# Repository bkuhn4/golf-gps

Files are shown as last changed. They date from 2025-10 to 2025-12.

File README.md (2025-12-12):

# EE 333 Pocket Caddy

## Description
Pocket Caddy is a handheld golf GPS and shot tracking device designed to help golfers track their performance and environmental conditions. It utilizes a high-precision u-blox GNSS module to measure shot distances and logs them to a micro SD card along with real-time temperature and humidity data. The device features an OLED display for easy navigation, a battery fuel gauge for power management, and a robust menu system for managing user profiles and reviewing shot history.

## Features
- **GPS Distance Tracking:** Calculates precise distances between shot start and end points using the Vincenty formula.
- **Shot Logging:** Records club used, distance, temperature, humidity, date, and time to an SD card.
- **Environmental Monitoring:** Real-time display of temperature and humidity using the SHT31 sensor.
- **Battery Management:** Monitors battery voltage, state of charge (SOC), and current consumption.
- **User Profiles:** Supports multiple user profiles for organizing shot data.
- **OLED Interface:** Clear, high-contrast menu system navigated via physical buttons.

## Hardware

The Pocket Caddy hardware is built around the ESP32-C3 microcontroller and includes the following components:

*   **Microcontroller:** Espressif ESP32-C3-WROOM-02
*   **GNSS Module:** u-blox NEO-M9N (High-precision GPS/GLONASS/Galileo)
*   **GNSS Antenna:** Taoglas SGGP.25.4.A.02
*   **Display:** 0.96" OLED I2C Display (128x64 pixels)
*   **Sensors:**
    *   Sensirion SHT30-DIS (Temperature & Humidity)
    *   TI BQ27441-G1 (LiPo Fuel Gauge)
*   **Storage:** Micro SD Card Slot
*   **Power:**
    *   USB-C Connector (Charging & Data)
    *   LiPo Battery Connector
    *   Coin Cell Battery Backup (for GNSS hot start)

## Pin Configuration

| Component | Pin Name | ESP32-C3 Pin |
| :--- | :--- | :--- |
| **Buttons** | Button 1 (Down) | GPIO 9 |
| | Button 2 (Up) | GPIO 20 |
| | Button 3 (Select) | GPIO 2 |
| **I2C Bus** | SDA | GPIO 10 |
| | SCL | GPIO 4 |
| **GPS** | Enable | GPIO 3 |
| | Reset | GPIO 21 |

## Dependencies

To compile the firmware, you will need to install the following libraries via the Arduino Library Manager:

*   **SparkFun u-blox GNSS Arduino Library** by SparkFun Electronics
*   **SparkFun BQ27441 LiPo Fuel Gauge Arduino Library** by SparkFun Electronics
*   **Adafruit SHT31 Library** by Adafruit
*   **U8g2** by olikraus

## Programming the Device

### First-Time Programming (Boot Mode)
When programming the device for the first time (or if it becomes unresponsive), you need to manually enter the bootloader mode:
1.  Hold down the **BOOT** button.
2.  While holding BOOT, press and release the **RESET** button.
3.  Release the **BOOT** button.
4.  The device is now in boot mode and ready to accept firmware.

### Arduino IDE Settings
To ensure the device communicates correctly over USB for serial monitoring and subsequent uploads:
1.  **Install Board Support:** Ensure the **esp32** board library by Espressif Systems is installed. If not, go to `Tools > Board > Boards Manager` and search `"esp32"`.
2.  **Select Board:** Go to `Tools > Board > esp32 > ESP32C3 Dev Module`.
3.  **USB CDC On Boot:** To avoid having to manually enter boot mode each time, go to `Tools > USB CDC On Boot > Enabled`.
4.  Select the correct COM port. `Tools > Port > COM#`.

## Usage

### Controls
The device is operated using three buttons:
-   **Button 1 (Down):** Navigate down in menus.
-   **Button 2 (Up):** Navigate up in menus.
-   **Button 3 (Select/Back):**
    -   **Short Press:** Select item / Confirm action.
    -   **Long Press:** Go back to the previous menu.

### Main Menu Options
-   **Track Shot:** Start a new shot tracking session. Mark your start point, go to your ball, mark the end point, and select the club used.
-   **Sensor View:** Displays raw sensor data including GPS coordinates (Lat/Lon), Satellite count (SIV), Temperature, Humidity, and Battery stats.
-   **Shot Log:** Review historical shot data organized by club.
-   **Settings:**
    -   **Units:** Toggle between Imperial (Yards/Fahrenheit) and Metric (Meters/Celsius).
    -   **Profiles:** Create, Rename, or Remove user profiles.

## Authors and acknowledgment
-   **Brady Kuhn**: Hardware | Software
-   **Bryan York**

## Project status
Active Development - Version 0.1

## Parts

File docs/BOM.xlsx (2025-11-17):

Quantity | Reference(s) | Description | Package | Part Number | Manufacturer | Vendor PN | Notes | Link
1 | AE1 | RF ANT 1.575/1.602GHZ CER PATCH |  | SGGP.25.2.A.02 | Taoglas Limited | 931-1450-1-ND |  | https://www.digikey.com/en/products/detail/taoglas-limited/SGGP-25-2-A-02/6362788?gclsrc=aw.ds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
1 | BT1 | 1500mAh LiPo Battery |  |  | GYMIN | B0CRP2G3XN | Amazon | https://www.amazon.com/GYMIN-Rechargeable-Replacement-Steelseries-Wireless/dp/B0CRP2G3XN
1 | BT2 | BATTERY RETAINER COIN 20MM SMD |  | 3002 | Keystone Electronics | 36-3002-ND | ETG Stock
7 | C1-C6, C8 | CAP CER 10UF 16V X5R 0805 | C0805 | CL21A106KOQNNNG | Samsung Electro-Mechanics | 1276-6455-1-ND | ETG Stock
8 | C7, C9, C11, C12, C15, C16, C19, C20 | CAP CER 0.1UF 50V X7R 0603 | C0603 | CL10B104KB8NNNC | Samsung Electro-Mechanics | 1276-1000-1-ND | ETG Stock
2 | C10, 21 | CAP CER 1UF 25V X5R 0603 | C0603 | CL10A105KA8NNNC | Samsung Electro-Mechanics | 1276-1102-1-ND | ETG Stock
2 | C13, C14 | CAP CER 18PF 50V C0G/NP0 0603 | C0603 | CL10C180JB81PNC | Samsung Electro-Mechanics | 1276-2208-1-ND
3 | D1, D3, D4 | LED RED CLEAR SMD 0805 | D0805 | LTST-C171KRKT | Lite-On Inc. | 160-1427-1-ND
1 | D2 | TVS DIODE 5.5VWM SOT143B | SOT-143B | PRTR5V0U2X,215 | Nexperia USA Inc. | 1727-3884-1-ND
2 | D5, D6 | LED GREEN CLEAR SMD 0805 | D0805 | LTST-C170GKT | Lite-On Inc. | 160-1179-1-ND | ETG Stock
1 | D7 | DIODE ARR SCHOTT 30V 200MA SOT23 | SOT-23 | BAT54C | Diotec Semiconductor | 4878-BAT54CCT-ND |  | https://www.digikey.com/en/products/detail/diotec-semiconductor/bat54c/13163831
1 | F1 | PTC RESET FUSE 6V 1A 1206 | 1206 | 0ZCJ0100FF2E | Bel Fuse Inc. | 5923-0ZCJ0100FF2ECT-ND
1 | J1 | CONN RCP USB2.0 TYP C 24P SMD RA |  | USB4105-GF-A | GCT | 2073-USB4105-GF-ACT-ND |  | https://www.digikey.com/en/products/detail/gct/usb4105-gf-a-120/14559037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
1 | J2 | TERM BLK 3P SIDE ENT 2.54MM PCB | P=2.54mm | 282834-3 | TE Connectivity | A98334-ND | ETG Stock
1 | J3 | Conn_01x03_Pin | P=2.54mm |  |  |  | ETG Stock
1 | J4 | Conn_02x04 | P=2.54mm |  |  |  | ETG Stock
1 | J5 | Conn_01x04 | P=2.54mm |  |  |  | ETG Stock
1 | J6 | CONN MICRO SD CARD R/A SMD |  | 1040310811 | Molex | WM6357CT-ND |  | https://www.digikey.com/en/products/detail/molex/1040310811/2370379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
1 | L1 | FIXED IND 1.5UH SMD |  | VLS3012CX-1R5M-1 | TDK Corporation | 445-VLS3012CX-1R5M-1CT-ND
1 | L2 |  |  |  |  |  | DNP. Use 0603 0 Ohm resistor
1 | Q1 | MOSFET P-CH 20V 4.2A SOT23 | SOT-23-3 | DMG2305UX-7 | Diodes Incorporated | DMG2305UX-7DICT-ND |  | https://www.digikey.com/en/products/detail/diodes-incorporated/dmg2305ux-7/4340667
2 | R1, R3 | RES 27 OHM 5% 1/10W 0603 | R0603 | RC0603JR-0727RL | YAGEO | 311-27GRCT-ND |  | https://www.digikey.com/en/products/detail/yageo/RC0603JR-0727RL/726751
1 | R2 | RES 1.3K OHM 5% 1/10W 0603 | R0603 | RC0603JR-071K3L | YAGEO | 311-1.3KGRCT-ND |  | https://www.digikey.com/en/products/detail/yageo/RC0603JR-071K3L/726686
8 | R4, R11-R13, R15-R18 | 10 kOhms ±1% 0.125W, 1/8W | R0603 | RNCP0603FTD10K0 | Stackpole Electronics Inc | RNCP0603FTD10K0CT-ND | ETG Stock
5 | R5, R8-R10, R14 | RES 1K OHM 1% 1/8W 0603 | R0603 | RNCP0603FTD1K00 | Stackpole Electronics Inc | RNCP0603FTD1K00CT-ND | ETG Stock
2 | R6, R7 | RES 5.1K OHM 1% 1/10W 0603 | R0603 | RMCF0603FT5K10 | Stackpole Electronics Inc | RMCF0603FT5K10CT-ND
1 | R19 | RES 0.01 OHM 1% 1W 1206 | R1206 | CSNL1206FT10L0 | Stackpole Electronics Inc | CSNL1206FT10L0CT-ND | 1% tolerance, 1W rating, 50ppm TCR
1 | R20 | RES 470K OHM 5% 1/8W 0805 | R0805 | RMCF0805JT470K | Stackpole Electronics Inc | RMCF0805JT470KCT-ND
2 | R21, R22 | RES 1M OHM 1% 1/8W 0805 | R0805 | RMCF0805FT1M00 | Stackpole Electronics Inc | RMCF0805FT1M00CT-ND
1 | SW1 | SWITCH SLIDE SPDT 200MA 30V | P=2.54mm | EG1218 | E-Switch | EG1903-ND | ETG Stock
4 | SW2-SW5 | SWITCH TACTILE SPST-NO 0.05A 12V |  |  |  |  | ETG Stock
1 | U1 | IC BATT CHG LI-ION 1CELL 20QFN | 20-VFQFN | MCP73871-1AAI/ML | Microchip Technology | MCP73871-1AAI/ML-ND |  | https://www.digikey.com/en/products/detail/microchip-technology/mcp73871-1aai-ml/7928179
1 | U2 | IC REG BUCK BST 3.3V 900MA 10SON | 10-WFDFN | TPS63031DSKR | Texas Instruments | 296-39461-1-ND |  | https://www.digikey.com/en/products/detail/texas-instruments/TPS63031DSKR/2048021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
1 | U3 | ESP32-C3-WROOM-02-H4 | 32-SMD Module | ESP32-C3-WROOM-02-H4 | Espressif Systems | 1965-ESP32-C3-WROOM-02-H4CT-ND |  | https://www.digikey.com/en/products/detail/espressif-systems/esp32-c3-wroom-02-h4/14553033
1 | U4 | M9 STANDARD PRECISION GNSS MOD | 24-SMD Module | NEO-M9N-00B | u-blox | 672-NEO-M9N-00BCT-ND |  | https://www.digikey.com/en/products/detail/u-blox/neo-m9n-00b/12149174
1 | U5 | SENSOR HUMID/TEMP 5V I2C 2% SMD | 8-VFDFN | SHT30-DIS-B2.5KS | Sensirion AG | 1649-1009-1-ND |  | https://www.digikey.com/en/products/detail/sensirion-ag/SHT30-DIS-B2-5KS/5872250
1 | U6 | IC FUEL GAUGE LI-ION 1CELL 12SON | 12-VFDFN | BQ27411DRZT-G1A | Texas Instruments | 296-37269-1-ND |  | https://www.digikey.com/en/products/detail/texas-instruments/BQ27427YZFR/17748369
1 | Y1 | CRYSTAL 32.7680KHZ 12.5PF SMD | 2-SMD (3.2x1.5) | ABS07-32.768KHZ-T | Abracon LLC | 535-9542-1-ND |  | https://www.digikey.com/en/products/detail/abracon-llc/ABS07-32-768KHZ-T/1236858
73 | Total Part Count

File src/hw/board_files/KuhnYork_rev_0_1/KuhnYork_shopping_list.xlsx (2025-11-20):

Digi-Key: Shopping Cart
Index | Quantity | Part Number | Manufacturer Part Number | Description | Customer Reference | Available | Backorder | Unit Price | Extended Price USD
1 | 2 | 931-1450-1-ND | SGGP.25.2.A.02 | RF ANT 1.575/1.602GHZ CER PATCH | KUHN, YORK | 2 | 0 | 7.2 | 14.40
2 | 2 | 4878-BAT54CCT-ND | BAT54C | DIODE ARR SCHOTT 30V 200MA SOT23 | KUHN, YORK | 2 | 0 | 0.12 | 0.24
3 | 2 | 1740-ESDALD05UJ2XCT-ND | ESDALD05UJ2X | TVS DIODE 5VWM 17VC SOT143 | KUHN, YORK | 2 | 0 | 0.47 | 0.94
4 | 2 | 2073-USB4105-GF-ACT-ND | USB4105-GF-A | CONN RCP USB2.0 TYP C 24P SMD RA | KUHN, YORK | 2 | 0 | 0.78 | 1.56
5 | 2 | 5923-0ZCJ0100FF2ECT-ND | 0ZCJ0100FF2E | PTC RESET FUSE 6V 1A 1206 | KUHN, YORK | 2 | 0 | 0.25 | 0.50
6 | 2 | WM6357CT-ND | 1040310811 | CONN MICRO SD CARD R/A SMD | KUHN, YORK | 2 | 0 | 2.04 | 4.08
7 | 2 | 445-VLS3012CX-1R5M-1CT-ND | VLS3012CX-1R5M-1 | FIXED IND 1.5UH SMD | KUHN, YORK | 2 | 0 | 0.24 | 0.48
8 | 18 | RNCP0603FTD10K0CT-ND | RNCP0603FTD10K0 | RES 10K OHM 1% 1/8W 0603 | KUHN, YORK | 18 | 0 | 0.011 | 0.20
9 | 10 | RNCP0603FTD1K00CT-ND | RNCP0603FTD1K00 | RES 1K OHM 1% 1/8W 0603 | KUHN, YORK | 10 | 0 | 0.01 | 0.10
10 | 2 | CSNL1206FT10L0CT-ND | CSNL1206FT10L0 | RES 0.01 OHM 1% 1W 1206 | KUHN, YORK | 2 | 0 | 0.58 | 1.16
11 | 2 | MCP73871-1AAI/ML-ND | MCP73871-1AAI/ML | IC BATT CHG LI-ION 1CELL 20QFN | KUHN, YORK | 2 | 0 | 2.41 | 4.82
12 | 2 | 296-39461-1-ND | TPS63031DSKR | IC REG BUCK BST 3.3V 900MA 10SON | KUHN, YORK | 2 | 0 | 2.14 | 4.28
13 | 2 | 296-37269-1-ND | BQ27411DRZT-G1A | IC FUEL GAUGE LI-ION 1CELL 12SON | KUHN, YORK | 2 | 0 | 3.18 | 6.36
14 | 2 | 1649-1009-1-ND | SHT30-DIS-B2.5KS | SENSOR HUMID/TEMP 5V I2C 2% SMD | KUHN, YORK | 2 | 0 | 2.7 | 5.40
15 | 2 | 535-9542-1-ND | ABS07-32.768KHZ-T | CRYSTAL 32.7680KHZ 12.5PF SMD | KUHN, YORK | 2 | 0 | 0.61 | 1.22

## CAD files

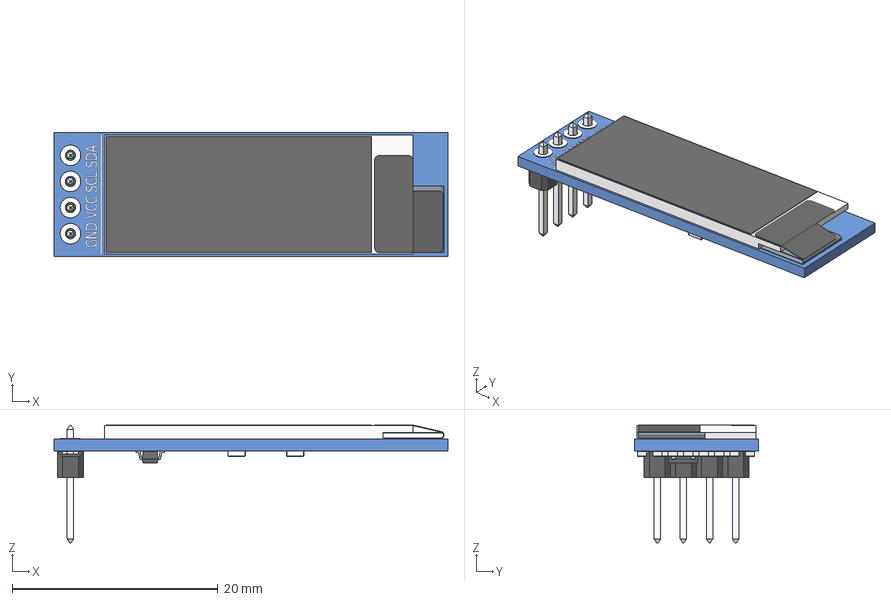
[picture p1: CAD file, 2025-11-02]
src/hw/board_files/3d_models/OLED_0.91_128x32.stp
38.3 x 12.1 x 11.5 mm
OLED_0.91_128x32
Pin Header 4 x 1 TH 2.54mm Pitch
RESC-0603 x 13
2SD0601A

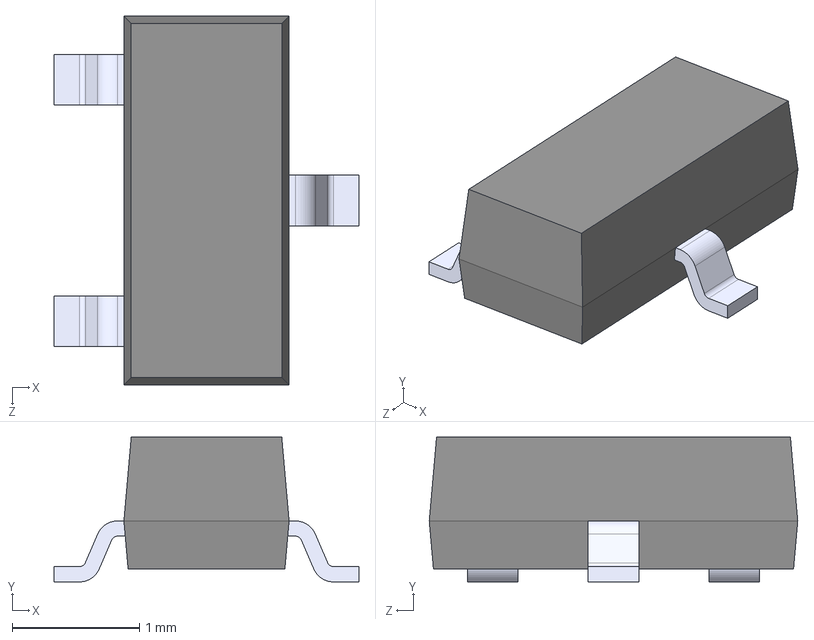
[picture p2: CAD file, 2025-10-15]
src/hw/board_files/3d_models/DMG2305UX-7.STEP
2.40 x 1.14 x 2.90 mm

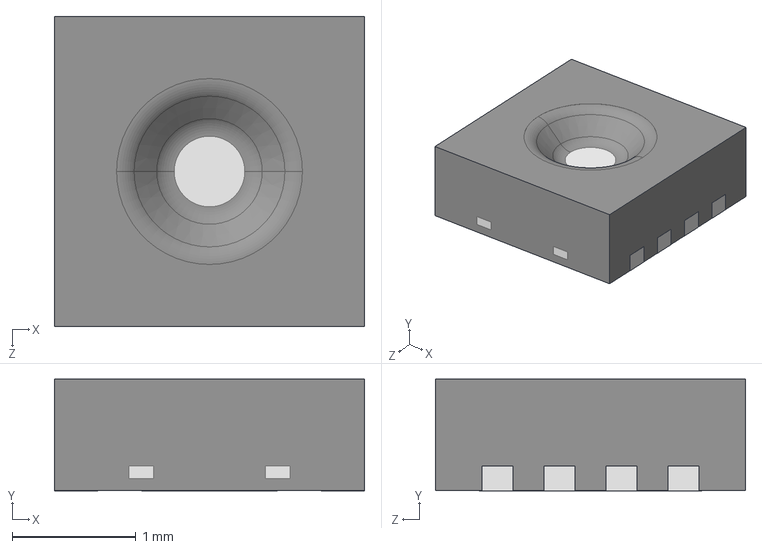
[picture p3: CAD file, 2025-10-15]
src/hw/board_files/3d_models/SHT30-DIS-B2.5KS.step
2.50 x 0.901 x 2.50 mm

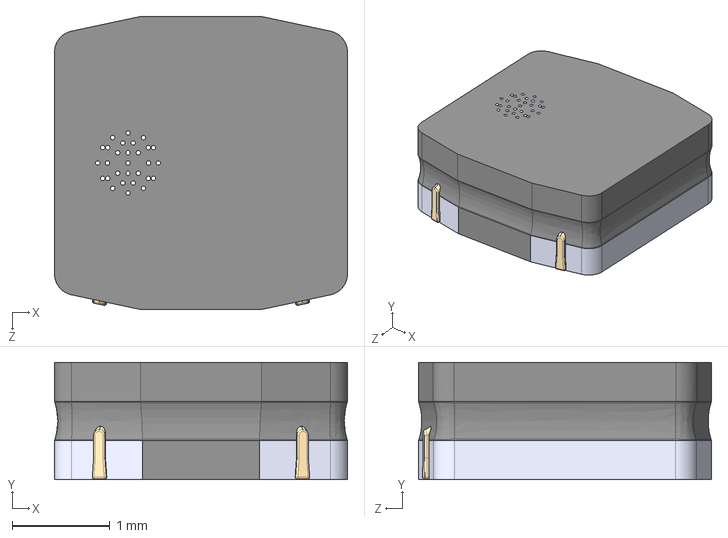
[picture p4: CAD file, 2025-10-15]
src/hw/board_files/3d_models/VLS3012CX-1R5M-1.STEP
3.00 x 1.20 x 3.00 mm

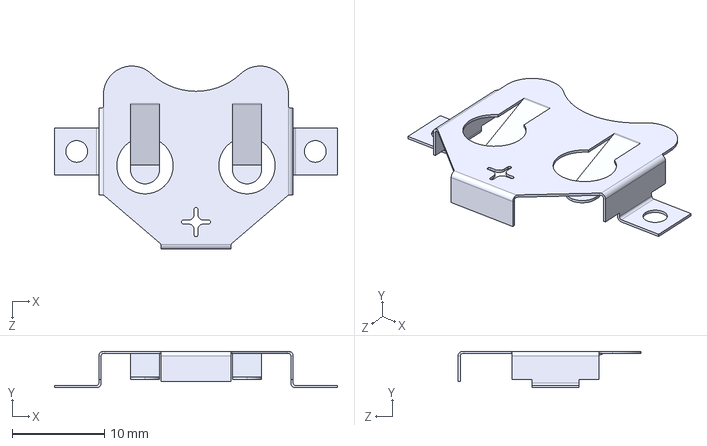
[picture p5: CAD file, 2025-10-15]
src/hw/board_files/3d_models/3002.step
30.7 x 3.96 x 19.9 mm

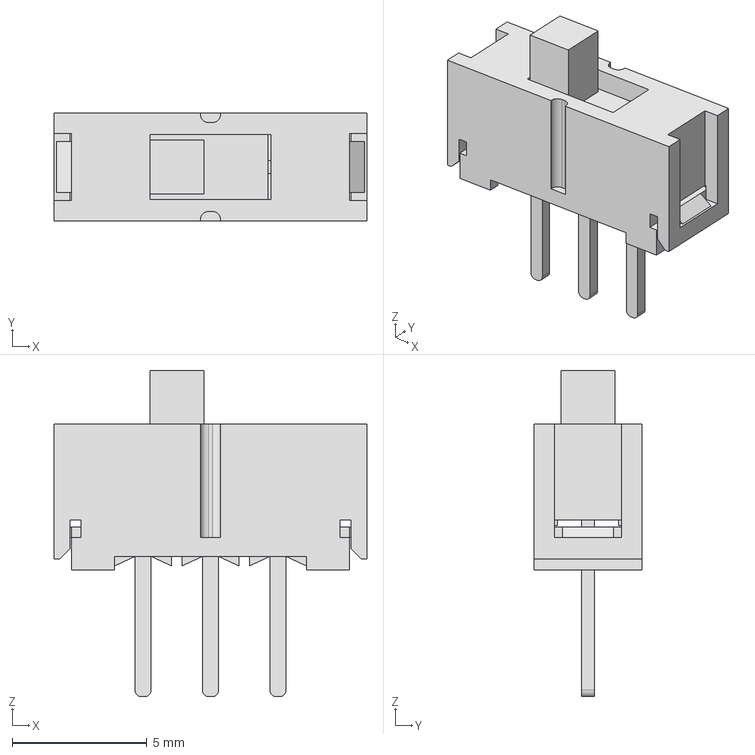
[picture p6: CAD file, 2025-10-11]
src/hw/board_files/3d_models/141_EG1218.stp
11.6 x 4.00 x 12.1 mm

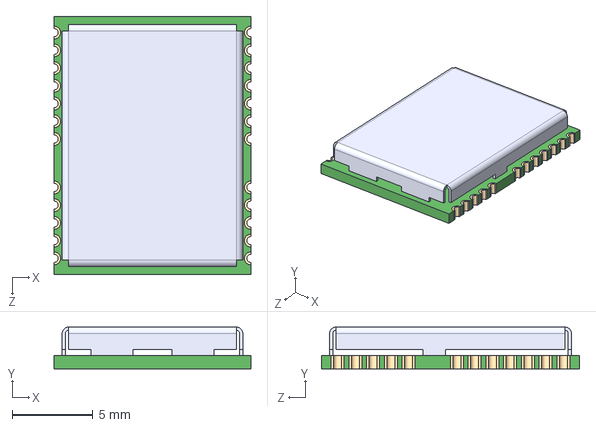
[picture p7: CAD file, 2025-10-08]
src/hw/board_files/3d_models/NEO-M9N-00B.STEP
12.2 x 2.60 x 16.0 mm

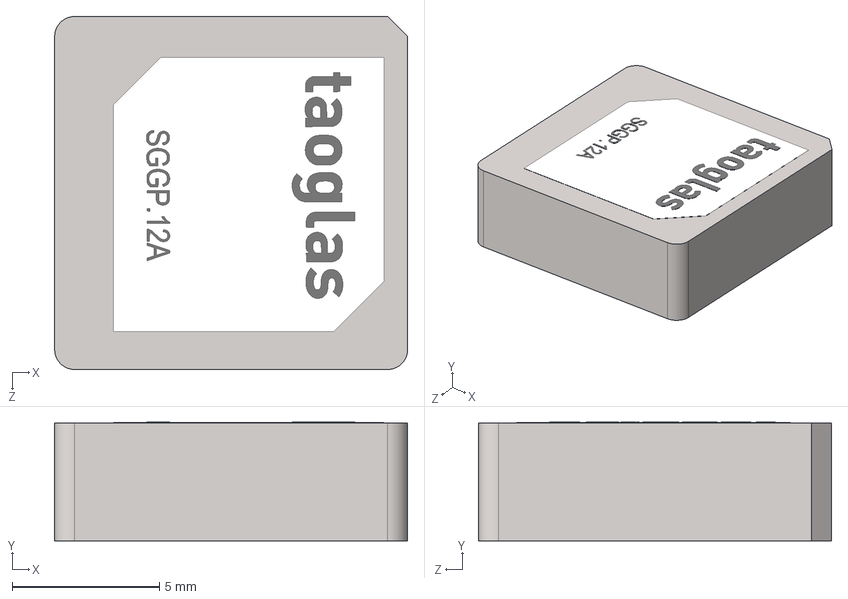
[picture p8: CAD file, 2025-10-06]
src/hw/board_files/3d_models/SGGP.12.4.A.02_Web.STEP
12.0 x 4.03 x 12.0 mm

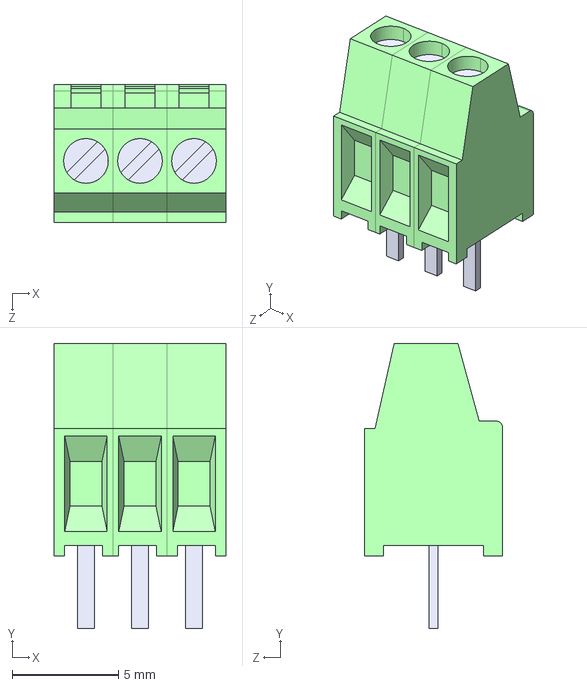
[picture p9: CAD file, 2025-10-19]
src/hw/board_files/3d_models/282834-3.STEP
8.08 x 13.4 x 6.50 mm

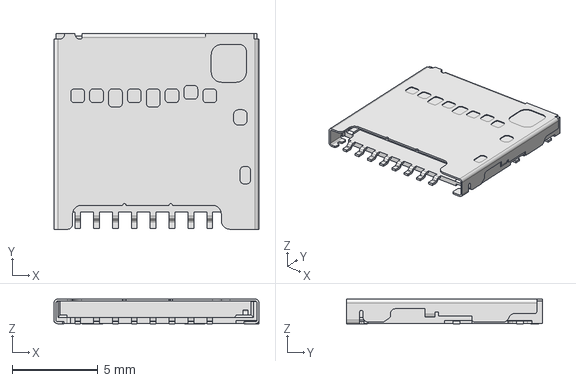
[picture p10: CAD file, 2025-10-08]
src/hw/board_files/3d_models/1040310811.stp
11.9 x 11.4 x 1.45 mm

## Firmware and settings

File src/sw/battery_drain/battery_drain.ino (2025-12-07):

#include <Wire.h>
#include <WiFi.h>
#include <Preferences.h>
#include <SparkFunBQ27441.h>
#include <Adafruit_GFX.h>
#include <Adafruit_SSD1306.h>

// --- HARDWARE CONFIG ---
#define SDA_PIN 10
#define SCL_PIN 4 

// --- BUTTONS (Adjust pins to match your PCB) ---
// Connect buttons between Pin and GND (Active LOW)
#define BTN_LOAD_PIN  9   // Button 1: Toggle High Load
#define BTN_SLEEP_PIN 20  // Button 2: Force Sleep/Relax
#define BTN_SAVE_PIN  2   // Button 3: Save Data

// --- BATTERY SETTINGS ---
#define DESIGN_CAPACITY 1500 
#define TERMINATE_VOLTAGE 3000 // 3.0V

Adafruit_SSD1306 display(128, 64, &Wire, -1);
Preferences preferences;

bool loadEnabled = false;
unsigned long lastButtonPress = 0;

// Helper to send GAUGE_EN (0x0021) since executeControlWord is private
bool enableGauge() {
  Wire.beginTransmission(0x55); // BQ27441 I2C Address
  Wire.write(0x00);             // Control() Command
  Wire.write(0x21);             // LSB of GAUGE_EN
  Wire.write(0x00);             // MSB of GAUGE_EN
  return Wire.endTransmission() == 0;
}

void setup() {
  Serial.begin(115200);
  Wire.begin(SDA_PIN, SCL_PIN);
  
  // Setup Buttons
  pinMode(BTN_LOAD_PIN, INPUT_PULLUP);
  pinMode(BTN_SLEEP_PIN, INPUT_PULLUP);
  pinMode(BTN_SAVE_PIN, INPUT_PULLUP);

  // Setup Wakeup Source (Any button press wakes the ESP32-C3)
  // Mask is a bitmask of pins. If using pins 3,4,5:
  // Note: ESP32-C3 Deep Sleep wakeup usually works best on RTC GPIOs.
  // We will assume standard GPIO wakeup for C3:
  esp_deep_sleep_enable_gpio_wakeup(BIT(BTN_LOAD_PIN) | BIT(BTN_SLEEP_PIN) | BIT(BTN_SAVE_PIN), ESP_GPIO_WAKEUP_GPIO_LOW);

  // Init OLED
  if(!display.begin(SSD1306_SWITCHCAPVCC, 0x3C)) { 
    Serial.println(F("OLED Fail")); for(;;);
  }
  display.clearDisplay();
  display.setTextColor(WHITE);

  // Init BQ27411
  if (!lipo.begin()) {
    display.setCursor(0,0);
    display.println("Gauge Not Found!");
    display.display();
    while (1);
  }

  // --- RESTORE DATA ---
  preferences.begin("bat_data", true);
  unsigned int savedCap = preferences.getUInt("learned_cap", 0);
  preferences.end();
  
  // If we have valid saved data, load it. Otherwise default.
  if (savedCap > 1000 && savedCap < 2000) {
    lipo.setCapacity(savedCap); 
  } else {
    lipo.setCapacity(DESIGN_CAPACITY);
  }
  
  // Force Learning Mode ON
  if (enableGauge()) {
    Serial.println("Gauge Enabled (Impedance Track)");
  } else {
    Serial.println("Failed to Enable Gauge");
  }

  // Print Wake Reason
  esp_sleep_wakeup_cause_t wakeup_reason = esp_sleep_get_wakeup_cause();
  if (wakeup_reason == ESP_SLEEP_WAKEUP_GPIO) {
      Serial.println("Woke up via Button!");
  }
}

void loop() {
  // 1. Read Gauge
  unsigned int volts = lipo.voltage();
  int current = lipo.current(AVG);
  unsigned int soc = lipo.soc();
  unsigned int fcc = lipo.capacity(FULL);

  // 2. Handle Buttons
  if (millis() - lastButtonPress > 300) { // Simple debounce
    
    // BUTTON 1: TOGGLE LOAD
    if (digitalRead(BTN_LOAD_PIN) == LOW) {
      loadEnabled = !loadEnabled;
      if (loadEnabled) {
        WiFi.mode(WIFI_AP);
        WiFi.softAP("Drainer", "12345678");
      } else {
        WiFi.mode(WIFI_OFF);
      }
      lastButtonPress = millis();
    }

    // BUTTON 2: FORCE SLEEP
    if (digitalRead(BTN_SLEEP_PIN) == LOW) {
      goToSleep();
    }

    // BUTTON 3: SAVE
    if (digitalRead(BTN_SAVE_PIN) == LOW) {
      saveData();
      lastButtonPress = millis();
    }
  }

  // 3. Update Display
  display.clearDisplay();
  display.setCursor(0,0);
  
  if (loadEnabled) display.println(">> DRAINING <<");
  else if (current > 50) display.println(">> CHARGING <<");
  else display.println("-- IDLE/READY --");

  display.setCursor(0, 15);
  display.setTextSize(2);
  display.print(volts/1000.0, 2); display.print("V");
  
  display.setTextSize(1);
  display.setCursor(80, 15);
  display.print(soc); display.println("%");

  display.setCursor(0, 35);
  display.print("I: "); display.print(current); display.println(" mA");
  display.print("FCC: "); display.print(fcc); display.println(" mAh");

  display.setCursor(0, 55);
  display.print("[1]Load [2]Slp [3]Sav");
  
  display.display();

  // 4. Auto-Cutoff Logic
  if (loadEnabled) {
     // Heavy math to generate heat/load
     double x = 10.0;
     for(int i=0; i<1000; i++) x = sqrt(x+i);
     
     // Automatic safety stop
     if (volts <= TERMINATE_VOLTAGE) {
        loadEnabled = false;
        WiFi.mode(WIFI_OFF);
        // We go to sleep automatically to allow relax
        goToSleep();
     }
  }
  
  delay(200);
}

void goToSleep() {
  display.clearDisplay();
  display.setCursor(0,20);
  display.setTextSize(2);
  display.println("SLEEPING...");
  display.setTextSize(1);
  display.println("Press Btn to Wake");
  display.display();
  delay(2000);
  
  // The setup() defined the wakeup pins.
  // Start Deep Sleep. Everything (OLED, WiFi, CPU) turns off.
  // BQ27411 stays ALIVE.
  esp_deep_sleep_start();
}

void saveData() {
  unsigned int currentCap = lipo.capacity(FULL);
  preferences.begin("bat_data", false);
  preferences.putUInt("learned_cap", currentCap);
  preferences.end();
  
  display.clearDisplay();
  display.setCursor(0,20);
  display.println("SAVED TO FLASH!");
  display.print("Val: "); display.println(currentCap);
  display.display();
  delay(2000);
}

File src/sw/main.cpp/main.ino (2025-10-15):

/******************************************************************************
 * PROJECT:     Pocket Caddy - Golf GPS
 * FILE:        PocketCaddy_GolfGPS.ino
 * AUTHOR:      Brady Kuhn, Bryan York
 * DATE:        10/15/2025
 * VERSION:     0
 *
 * REQUIRED LIBRARIES:
 * - Wire.h                                (Built-in)
 * - SPI.h                                 (Built-in)
 * - SD.h                                  (Built-in with ESP32 core)
 * - Adafruit GFX Library                  (by Adafruit)
 * - Adafruit SSD1306                      (by Adafruit)
 * - SparkFun u-blox GNSS Arduino Library  (by SparkFun Electronics)
 * - SparkFun BQ27441 LiPo Fuel Gauge      (by SparkFun Electronics)
 * - Adafruit SHT31 Library                (by Adafruit)
 *
 * TODO: 
 *
 ******************************************************************************/

// --- PIN DEFINITIONS ---

// I2C Bus Pins (for OLED, Fuel Gauge, Temp/Hum Sensor, and GPS Module)
#define SCL_PIN         4   // I2C Clock
#define SDA_PIN         10  // I2C Data

// GPS Module Control Pins (Power and Reset)
#define GPS_EN_N_PIN    3
#define GPS_RESET_N_PIN 2

// SPI Bus Pin (for MicroSD Card)
#define SD_CS_PIN       5   // SPI Chip Select

// User Input Buttons
#define BTN_1_PIN       9   // BOOT button
#define BTN_2_PIN       20
#define BTN_3_PIN       21

// --- SETUP FUNCTION ---
void setup() {
  // Start serial for debugging output
  Serial.begin(115200);
  Serial.println("\n--- Pocket Caddy: Initializing GPIO Pins (I2C GPS) ---");

  // Initialize Button Pins
  pinMode(BTN_1_PIN, INPUT_PULLUP);
  pinMode(BTN_2_PIN, INPUT_PULLUP);
  pinMode(BTN_3_PIN, INPUT_PULLUP);
  Serial.println("Button pins initialized.");

  // Initialize GPS Control Pins
  pinMode(GPS_EN_N_PIN, OUTPUT);
  pinMode(GPS_RESET_N_PIN, OUTPUT);
  digitalWrite(GPS_EN_N_PIN, HIGH);   // Default state: GPS powered ON
  digitalWrite(GPS_RESET_N_PIN, HIGH); // Default state: GPS not in reset
  Serial.println("GPS control pins initialized.");

  // Initialize SD Card Chip Select Pin
  pinMode(SD_CS_PIN, OUTPUT);
  digitalWrite(SD_CS_PIN, HIGH); // Default state: SD card not selected
  Serial.println("SD Card CS pin initialized.");

  // Note: The I2C pins (SDA, SCL) and SPI pins (MOSI, MISO, SCK)
  // are configured by their respective library `begin()` calls (e.g., Wire.begin()).
  // No explicit pinMode() is needed for them here.

  Serial.println("\n--- Pin initialization complete. ---");
}

// --- MAIN LOOP ---
void loop() {
  // Intentionally empty.
}

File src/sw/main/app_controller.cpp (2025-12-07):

#include "app_controller.h"
#include "menu_handler.h" // Need full definition for drawActionScreen

AppController::AppController() {
    currentSensorView = 0;
    useMetric = false;
    currentClubIcon = nullptr;
    state = STATE_IDLE;
}

void AppController::begin(SdCardHandler* sdCardObj, GpsHandler* gpsObj, TempHumidSensor* tempObj, BatteryFuelGauge* batObj, TrackShot* trackShotObj) {
    sdCard = sdCardObj;
    gps = gpsObj;
    tempSensor = tempObj;
    battery = batObj;
    trackShot = trackShotObj;

    if (sdCard) {
        SystemSettings settings = sdCard->loadSettings();
        useMetric = settings.useMetric;
    }
}

void AppController::refreshChangeProfileMenu(MenuItem* menuItems) {
    if (!sdCard) return;
    Serial.println("Refreshing Change Profile Menu...");

    SystemSettings settings = sdCard->loadSettings();

    for (int i = 0; i < 5; i++) {
        menuItems[SETTINGS_CHANGE_SLOT_1 + i].title = "";
        menuItems[SETTINGS_CHANGE_SLOT_1 + i].isAction = true;
    }

    int count = sdCard->getProfiles(profileNames, 5);
    
    for (int i = 0; i < count; i++) {
        menuItems[SETTINGS_CHANGE_SLOT_1 + i].title = profileNames[i];
        if (strcmp(profileNames[i], settings.currentProfile) == 0) {
            menuItems[SETTINGS_CHANGE_SLOT_1 + i].icon = epd_bitmap_check_icon;
        } else {
            menuItems[SETTINGS_CHANGE_SLOT_1 + i].icon = epd_bitmap_user_icon;
        }
    }

    int backIndex = SETTINGS_CHANGE_SLOT_1 + count;
    menuItems[backIndex].title = "Back";
    menuItems[backIndex].icon = epd_bitmap_back_arrow_icon;
    menuItems[backIndex].isAction = false;
    
    menuItems[SETTINGS_PROFILES_CHANGE].numChildren = count + 1;
}

void AppController::refreshRemoveProfileMenu(MenuItem* menuItems) {
    if (!sdCard) return;
    Serial.println("Refreshing Remove Profile Menu...");

    for (int i = 0; i < 5; i++) {
        menuItems[SETTINGS_REMOVE_SLOT_1 + i].title = "";
        menuItems[SETTINGS_REMOVE_SLOT_1 + i].isAction = true;
    }

    int count = sdCard->getProfiles(profileNames, 5);
    
    for (int i = 0; i < count; i++) {
        menuItems[SETTINGS_REMOVE_SLOT_1 + i].title = profileNames[i];
        menuItems[SETTINGS_REMOVE_SLOT_1 + i].icon = epd_bitmap_user_icon;
    }

    int backIndex = SETTINGS_REMOVE_SLOT_1 + count;
    menuItems[backIndex].title = "Back";
    menuItems[backIndex].icon = epd_bitmap_back_arrow_icon;
    menuItems[backIndex].isAction = false;
    
    menuItems[SETTINGS_PROFILES_REMOVE].numChildren = count + 1;
}

void AppController::refreshRenameProfileMenu(MenuItem* menuItems) {
    if (!sdCard) return;
    Serial.println("Refreshing Rename Profile Menu...");

    for (int i = 0; i < 5; i++) {
        menuItems[SETTINGS_RENAME_SLOT_1 + i].title = "";
        menuItems[SETTINGS_RENAME_SLOT_1 + i].isAction = true;
    }

    int count = sdCard->getProfiles(profileNames, 5);
    
    for (int i = 0; i < count; i++) {
        menuItems[SETTINGS_RENAME_SLOT_1 + i].title = profileNames[i];
        menuItems[SETTINGS_RENAME_SLOT_1 + i].icon = epd_bitmap_user_icon;
    }

    int backIndex = SETTINGS_RENAME_SLOT_1 + count;
    menuItems[backIndex].title = "Back";
    menuItems[backIndex].icon = epd_bitmap_back_arrow_icon;
    menuItems[backIndex].isAction = false;
    
    menuItems[SETTINGS_PROFILES_RENAME].numChildren = count + 1;
}

void AppController::refreshUnitsMenu(MenuItem* menuItems) {
    Serial.println("Refreshing Units Menu...");
    if (useMetric) {
        menuItems[SETTINGS_UNITS_IMPERIAL].icon = epd_bitmap_blank_icon;
        menuItems[SETTINGS_UNITS_METRIC].icon = epd_bitmap_check_icon;
    } else {
        menuItems[SETTINGS_UNITS_IMPERIAL].icon = epd_bitmap_check_icon;
        menuItems[SETTINGS_UNITS_METRIC].icon = epd_bitmap_blank_icon;
    }
}

void AppController::refreshShotLogClubs(MenuItem* menuItems) {
    if (!sdCard) return;
    Serial.println("Refreshing Shot Log Clubs...");

    SystemSettings settings = sdCard->loadSettings();
    
    for (int i = 0; i < 5; i++) {
        menuItems[SL_CLUB_SLOT_1 + i].title = "";
        menuItems[SL_CLUB_SLOT_1 + i].isAction = false;
        menuItems[SL_CLUB_SLOT_1 + i].firstChild = SL_SHOT_SLOT_1;
        menuItems[SL_CLUB_SLOT_1 + i].numChildren = 0;
    }

    int count = sdCard->getUsedClubs(settings.currentProfile, clubNames, 5);

    for (int i = 0; i < count; i++) {
        menuItems[SL_CLUB_SLOT_1 + i].title = clubNames[i];
        menuItems[SL_CLUB_SLOT_1 + i].icon = epd_bitmap_club_icon;
    }

    int backIndex = SL_CLUB_SLOT_1 + count;
    menuItems[backIndex].title = "Back";
    menuItems[backIndex].icon = epd_bitmap_back_arrow_icon;
    menuItems[backIndex].isAction = false;
    menuItems[backIndex].parent = MAIN_SHOT_LOG;

    menuItems[MAIN_SHOT_LOG].numChildren = count + 1;
}

void AppController::refreshShotLogShots(MenuItem* menuItems, const char* club) {
    if (!sdCard) return;
    Serial.print("Refreshing Shot Log Shots for Club: ");
    Serial.println(club);

    SystemSettings settings = sdCard->loadSettings();
    
    for (int i = 0; i < 5; i++) {
        menuItems[SL_SHOT_SLOT_1 + i].title = "";
        menuItems[SL_SHOT_SLOT_1 + i].isAction = true;
    }

    int count = sdCard->getShotsForClub(settings.currentProfile, club, shotCache, 5);

    for (int i = 0; i < count; i++) {
        float dist = shotCache[i].distance;
        int day = (shotCache[i].date / 10000) % 100;
        int month = (shotCache[i].date / 100) % 100;
        
        snprintf(shotTitles[i], 32, "%.0f%s %d/%d", dist, useMetric ? "m" : "y", month, day);
        menuItems[SL_SHOT_SLOT_1 + i].title = shotTitles[i];
        menuItems[SL_SHOT_SLOT_1 + i].icon = epd_bitmap_placeholder_icon;
    }

    int backIndex = SL_SHOT_SLOT_1 + count;
    menuItems[backIndex].title = "Back";
    menuItems[backIndex].icon = epd_bitmap_back_arrow_icon;
    menuItems[backIndex].isAction = false;
}
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

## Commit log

2025-06-18 Changed to stand alone STM32. Added battery charger, USB C, and more.
    [golf-gps.kicad_pcb, golf-gps.kicad_sch, power.kicad_sch]
2025-06-19 Added BOM file, finishing sch
    [BOM-golf-gps.xlsx, golf-gps.kicad_sch, microcontroller.kicad_sch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]
2025-06-26 Added PI filter to antenna.
    [golf-gps.kicad_sch, microcontroller.kicad_sch, peripherals.kicad_sch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]
2025-06-27 Finished sch, started power section on PCB
    [golf-gps.kicad_pcb, golf-gps.kicad_sch, microcontroller.kicad_sch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]
2025-07-08 PCB Progress
    [golf-gps.kicad_pcb, peripherals.kicad_sch, power.kicad_sch]
2025-07-16 Added USBC to UART bridge for programming. Changed pinout. Added pinout spreadsheet in docs.
    [Golf GPS Pinout.xlsx, golf-gps.kicad_pcb, microcontroller.kicad_sch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]
2025-07-17 Finished new sch. Updated pinout. Started new PCB.
    [Golf GPS Pinout.xlsx, golf-gps.kicad_pcb, golf-gps.kicad_sch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]
2025-07-22 Removed USB to UART bridge, added VDDA decoupling, adjusted MCU pinout and updated spreadsheet
    [Golf GPS Pinout.xlsx, golf-gps.kicad_pcb, golf-gps.kicad_sch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]
2025-07-23 Updated pinout and spreadsheet, PCB changes
    [Golf GPS Pinout.xlsx, golf-gps.kicad_pcb, golf-gps.kicad_sch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]
2025-08-01 Figured out general component placement and made progress routing. Removed pullup resistor from MOSI, MISO, and SCK lines
    [golf-gps.kicad_pcb, peripherals.kicad_sch]
2025-08-02 Started filling out BOM
    [BOM-golf-gps.xlsx, golf-gps.kicad_pcb, golf-gps.kicad_sch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]
2025-08-06 PCB progress. Changed horizontal programming header to vertical.
    [golf-gps.kicad_pcb, microcontroller.kicad_sch, peripherals.kicad_sch]
2025-09-20 Started ESP32 schematic
    [BOM.xlsx, Golf GPS Pinout.xlsx, golf-gps.kicad_pcb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]
2025-09-22 Minor schematic changes
    [power.kicad_sch]
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2025-09-27 Put USB to UART bridge back and added jumpers to USB lines
    [microcontroller.kicad_sch, peripherals.kicad_sch, power.kicad_sch]
2025-09-29 Added fuel gauge if, push buttons, jumpers. Need to add test points then review schematic.
    [microcontroller.kicad_sch, peripherals.kicad_sch, pocket-caddy.kicad_sch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]
2025-09-29 Added Test Points to Schematic
    [microcontroller.kicad_sch, peripherals.kicad_sch, pocket-caddy.kicad_sch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]
2025-09-29 Swapped LiPo charging IC to a smarter one prevents the system from drawing battery power when USB is plugged in
    [peripherals.kicad_sch, pocket-caddy.kicad_sch, power.kicad_sch]
2025-10-01 Changed some jumpers to 3 pin headers
    [microcontroller.kicad_sch, power.kicad_sch]
2025-10-01 Added parts for new IC
    [BOM.xlsx, microcontroller.kicad_sch, peripherals.kicad_sch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]
2025-10-03 Added more footprints and test points
    [microcontroller.kicad_sch, peripherals.kicad_sch, pocket-caddy.kicad_sch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]
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2025-10-05 Started Layout. Still Need Antenna & LCD Screen added
    [microcontroller.kicad_sch, peripherals.kicad_sch, pocket-caddy.kicad_pcb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]
2025-10-05 Added LCD to Schematic
    [microcontroller.kicad_sch, peripherals.kicad_sch, pocket-caddy.kicad_pcb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]
2025-10-06 Started working on layout traces
    [pocket-caddy.kicad_pcb]
2025-10-06 Changed a footprint and made some minor changes.
    [microcontroller.kicad_sch, pocket-caddy.kicad_pcb]
2025-10-06 Started BOM, changed micrsoSD card slot and some other footprint. Will need to update layout.
    [BOM.xlsx, microcontroller.kicad_sch, peripherals.kicad_sch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]
2025-10-06 Made antenna footprint. Making new branch to try new LCD and layout
    [SGGP.12.4.A.02_Web.STEP, peripherals.kicad_sch, pocket-caddy.kicad_pcb]
2025-10-06 Moved some things around, revised regulator layout
    [BOM.xlsx, microcontroller.kicad_sch, peripherals.kicad_sch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]
2025-10-08 Lots of layout progress, changed some references (need to update BOM)
    [1040310811.stp, BOM.xlsx, NEO-M9N-00B.STEP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]
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2025-10-11 Added 3D model for power switch
    [141_EG1218.stp, pocket-caddy.kicad_pcb]
2025-10-12 Worked on BOM List
    [BOM.xlsx]
2025-10-13 Updated BOM, calculated TBD capacitor values
    [BOM.xlsx, microcontroller.kicad_sch]
2025-10-14 Changed fuel gauge IC. Need to update component references and BOM.
    [microcontroller.kicad_sch, peripherals.kicad_sch, pocket-caddy.kicad_pcb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]
2025-10-15 Layout progress. Made new footprint for inductor. Changed test points to pads
    [3002.step, VLS3012CX-1R5M-1.STEP, peripherals.kicad_sch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]
2025-10-15 Nearly done with layout
    [DMG2305UX-7.STEP, SHT30-DIS-B2.5KS.step, microcontroller.kicad_sch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]
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2025-10-15 BOM work can be overwritten
    [BOM.xlsx]
2025-10-16 Updated terminal block PN, generated gerbers and zip file for submission
    [282834-3.STEP, BOM.xlsx, microcontroller.kicad_sch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]
2025-10-17 Started hardware test program. Found required libraries
    [BOM.xlsx, microcontroller.kicad_sch]
2025-10-17 Added Digikey shopping list to KuhnYork.zip
    [KuhnYork.xlsx]
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2025-11-02 Added OLED 3D model
    [OLED_0.91_128x32.stp, pocket-caddy.kicad_pcb]
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2025-11-05 Fixed BOM details
    [BOM.xlsx, KuhnYork.xlsx]
2025-11-11 Initial commit, fixed esp enable RC delay circuit
    [microcontroller.kicad_sch, pocket-caddy.kicad_pcb]
2025-11-16 Fixed fuel gauge IC schematic
    [microcontroller.kicad_sch, peripherals.kicad_sch]
2025-11-17 Added new OLED footprint. Finished schematic updates, started lyout. Changed 10 mOhm sense resistor PN to TCR of 50 ppm/C
    [BOM.xlsx, microcontroller.kicad_sch, peripherals.kicad_sch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]
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2025-11-19 New layout done, need to make gerbers
    [microcontroller.kicad_sch, peripherals.kicad_sch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]
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
